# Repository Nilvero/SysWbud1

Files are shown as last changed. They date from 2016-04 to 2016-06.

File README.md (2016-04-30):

# Systemy wbudowane projekt
Projekt stacji pogodowej z wykorzystaniem wyświetlacza dotykowego opartej o Cortex-M4F.

## Części:
- płytka ewaluacyjna [STM32F429I](http://www2.st.com/content/ccc/resource/technical/document/data_brief/ff/c1/b6/02/c3/b4/49/cb/DM00094498.pdf/files/DM00094498.pdf/jcr:content/translations/en.DM00094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)
- czujnik wewnętrzny temperatury i wilgotności [DHT-11](http://www.micropik.com/PDF/dht11.pdf) 
- termometr cyfrowy zewnętrzny [DS18B20](https://datasheets.maximintegrated.com/en/ds/DS18B20.pdf) (1-wire)
- moduł czujnika poziomu CO_2 w pomieszczeniu oparty na [MG811](http://www.dfrobot.com/image/data/SEN0159/CO2b%20MG811%20datasheet.pdf) (analog)
- barometr cyfrowy [LPS331](http://www2.st.com/content/ccc/resource/technical/document/datasheet/40/c2/46/1e/99/22/4c/60/DM00036196.pdf/files/DM00036196.pdf/jcr:content/translations/en.DM000361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) (SPI/I2C)
- demodulator podczerwieni [TSOP31230](http://www.vishay.com/docs/82492/tsop312.pdf) (przerwanie EXT_x i timer) 
- czujnik poziomu pyłów w powietrzu [GP2Y1010AU0F](https://www.sparkfun.com/datasheets/Sensors/gp2y1010au_e.pdf) (analog)
- pilot do tunera telewizyjnego Hama

Wstępny schemat części elektronicznej (dzielniki napięcia prawdopodobnie zostaną poprzedzone wtórnikami)
[link](https://github.com/KrzysztofStachanczyk/SysWbud1/blob/master/electronic_schem.pdf)

W ramach projektu zostanie wykonana również shield z w.w. sensorami.

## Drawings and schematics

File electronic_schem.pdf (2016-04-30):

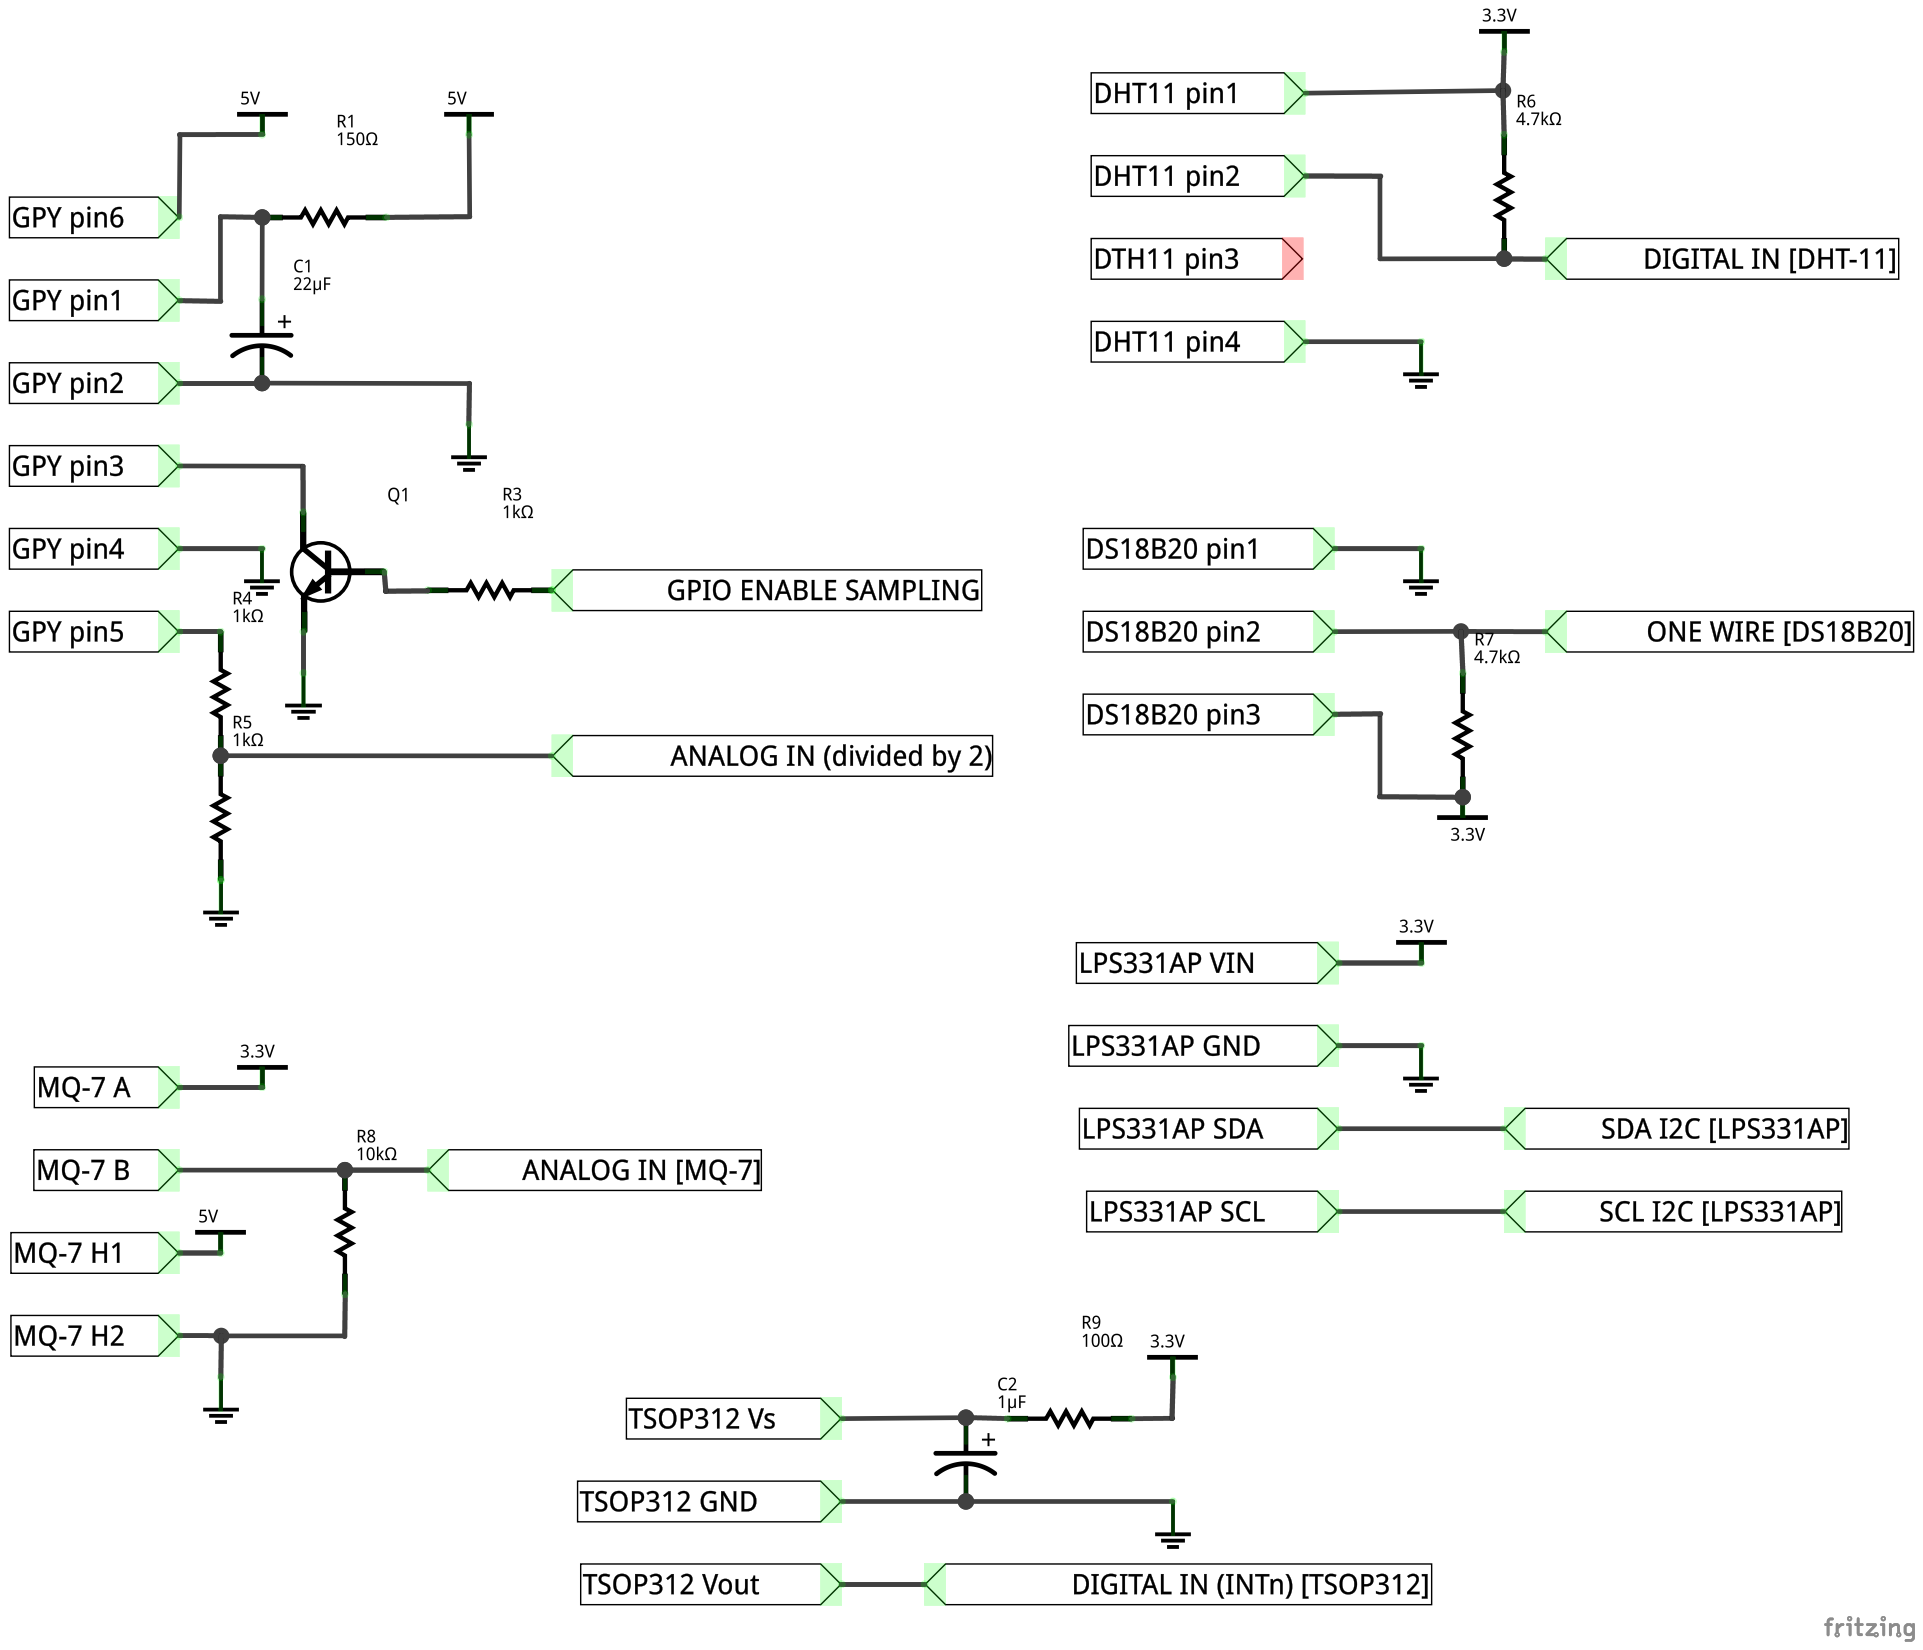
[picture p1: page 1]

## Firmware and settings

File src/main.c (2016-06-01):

/**
*****************************************************************************
**
**  File        : main.c
**
**  Abstract    : main function.
**
**  Functions   : main
**
**  Environment : Atollic TrueSTUDIO(R)
**                STMicroelectronics STM32F4xx Standard Peripherals Library
**
**  Distribution: The file is distributed "as is", without any warranty
**                of any kind.
**
**  (c)Copyright Atollic AB.
**  You may use this file as-is or modify it according to the needs of your
**  project. This file may only be built (assembled or compiled and linked)
**  using the Atollic TrueSTUDIO(R) product. The use of this file together
**  with other tools than Atollic TrueSTUDIO(R) is not permitted.
**
*****************************************************************************
*/

/* Includes */
#include "stm32f4xx.h"
#include "stm32f429i_discovery.h"
#include "stm32f429i_discovery_ioe.h"
#include "DHT11.h"
#include "ds18b20.h"
#include "LPS331.h"
#include "SharedFunctions.h"
#include "MainMenu.h"
#include "Results.h"

#define MEASURE_INTERVAL_MS 2000
static unsigned counter;

void delayDec(void)
{
    if(counter>0){
        counter--;
    }
    else{
		collectDataFromSensors();
    	counter=MEASURE_INTERVAL_MS;
    }
}

void SysTick_Handler(void)
{
   delayDec();
}

int main(void)
{
   LPS331_INIT();
   LCDinit();
   DMArecordPushInit();
   results.sampleNumber=0;

   counter=MEASURE_INTERVAL_MS;

   SysTick_Config(SystemCoreClock / 1000);
  /* Infinite loop */
   while (1)
   {
	  MainMenu();
   }
}




/*
 * Callback used by stm324xg_eval_i2c_ee.c.
 * Refer to stm324xg_eval_i2c_ee.h for more info.
 */
uint32_t sEE_TIMEOUT_UserCallback(void)
{
  while (1)
  {
  }
}

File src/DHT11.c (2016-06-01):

/*
 * DHT11.c
 *
 *  Created on: Apr 10, 2016
 *      Author: krzys
 */

#include "DHT11.h"
#include "SharedFunctions.h"

void DHT11SentStartRequest(){
	// high logic level by default (pull-up line)
	GPIOG->ODR |= (1<<5);

	// set as output
	GPIOG->MODER |= (uint32_t)(1<<10);
	GPIOG->MODER &= ~((uint32_t)(1<<11));

	// high speed output enable
	GPIOG->OSPEEDR|=(uint32_t)(1<<11);
	GPIOG->OSPEEDR&= ~((uint32_t)(1<<10));

	// open-drain
	GPIOG->OTYPER |= ((uint32_t)(1<<5));

	// no pull-up (external pull-up)
	GPIOG->PUPDR &= ~((uint32_t)(1<<10));
	GPIOG->PUPDR &= ~((uint32_t)(1<<11));

	// reset value
	TIM2->CNT = 0x00;

	// start timer
	TIM2->CR1 |= 0x01;

	// wait 20 ms
	while(TIM2->CNT<20000){
		__NOP();
	}

	// pull data line down && wait 20 ms
	GPIOG->ODR&=~((uint32_t)(1<<5));
	TIM2->CNT = 0x00;
	while(TIM2->CNT<20000){
		__NOP();
	}

	// pull data line up
	GPIOG->ODR |=((uint32_t)(1<<5));
}
uint32_t DHT11RecvData(uint32_t * intervalsArray){
	uint16_t state=GPIOG->IDR & (1<<5);

	// listen for new data
	int dataNumber;
	for(dataNumber=0;dataNumber<42;dataNumber++){
		// reset timer value
		TIM2->CNT=0;
		//start timer
		TIM2->CR1|=0x01;

		// wait for logical level change or timeout
		while(TIM2->CNT<500 && (GPIOG->IDR & (1<<5))==state){
			__NOP();
		}

		// stop timer
		TIM2->CR1 &= ~0x00000001;

		// if timeout return error code
		if(TIM2->CNT>=500){
			if(dataNumber==0){
				return DHT11_NO_RESPONSE;
			}
			else{
				return DHT11_TIME_OUT;
			}
		}

		// read new logical state
		state=GPIOG->IDR & (1<<5);

		if(!state){
			// save active state time
			intervalsArray[dataNumber]=TIM2->CNT;
		}
		else
		{
			// ignore inactive states
			dataNumber--;
		}
	}
	return DHT11_OK;
}
uint32_t DHT11DecodeByte(uint32_t * intervals,uint8_t * result){
	int index;
	*result=0;
	for(index=0;index<8;index++){
		if(intervals[index]>10 && intervals[index]<40){
			*result=(*result)<<1;
		}
		else if(intervals[index]>50 && intervals[index]<90){
			*result=((*result)<<1) + 0x01;
		}
		else{
			return DHT11_DECODE_ERROR;
		}
	}
	return DHT11_OK;
}

void DHT11Decode(uint32_t * intervals,DHT11Result * result){

	// decode RH integral
	uint8_t RH_integral=0;
	result->ERROR_CODE=DHT11DecodeByte(&intervals[2],&RH_integral);
	if(result->ERROR_CODE!=DHT11_OK){ return; }

	// decode RH decimal
	uint8_t RH_decimal=0;
	result->ERROR_CODE=DHT11DecodeByte(&intervals[10],&RH_decimal);
	if(result->ERROR_CODE!=DHT11_OK){ return; }

	//decode T integral
	uint8_t T_integral=0;
	result->ERROR_CODE=DHT11DecodeByte(&intervals[18],&T_integral);
	if(result->ERROR_CODE!=DHT11_OK){ return; }

	//decode T decimal
	uint8_t T_decimal=0;
	result->ERROR_CODE=DHT11DecodeByte(&intervals[26],&T_decimal);
	if(result->ERROR_CODE!=DHT11_OK){ return; }

	//decode CRC
	uint8_t CRC_value=0;
	result->ERROR_CODE=DHT11DecodeByte(&intervals[34],&CRC_value);
	if(result->ERROR_CODE!=DHT11_OK){ return; }

	//check CRC
	uint8_t countedCRC=T_integral+T_decimal+RH_decimal+RH_integral;
	if(countedCRC!=CRC_value){
		result->ERROR_CODE=DHT11_CRC_ERROR;
		return;
	}

	//join decimal with integral (compability with dht-22)
	result->humidity=(float)(RH_decimal/10+RH_integral);
	result->temperature=(float)(T_decimal/10+T_integral);
}
DHT11Result DHT11_read(){
	uint32_t intervals[42];

	// check if port D enable if not enable it
	if((RCC->AHB1ENR & RCC_AHB1Periph_GPIOG)==0){
		RCC->AHB1ENR |= RCC_AHB1Periph_GPIOG;
	}

	DHT11Result result;

	InitTimerTIM2ToCountInUc();
	DHT11SentStartRequest();
	result.ERROR_CODE=DHT11RecvData(intervals);

	if(result.ERROR_CODE!=DHT11_OK){
		return result;
	}
	// disable timer2
	TIM2->CR1 &= ~0x00000001;

	DHT11Decode(intervals,&result);

	return result;
}

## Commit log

2016-04-14 DHT 11 Errors detection improved
    [DHT11.c, main.c]
2016-04-25 Electronic prototype
    [electronic.fzz]
2016-04-25 Schematic in SVG
2016-04-26 Change DS18B20 Pin to PG4
2016-04-30 LPS331 support without error detection (timeout error) - I2C2 [ port F pins 0,1 ]
    [LPS331.c, main.c]
2016-05-01 RTC basic support and moving I2C2 init procedure to SharedFunctions file
2016-05-27 CO2 SENSOR
2016-06-01 Integracja modułów + DMA
